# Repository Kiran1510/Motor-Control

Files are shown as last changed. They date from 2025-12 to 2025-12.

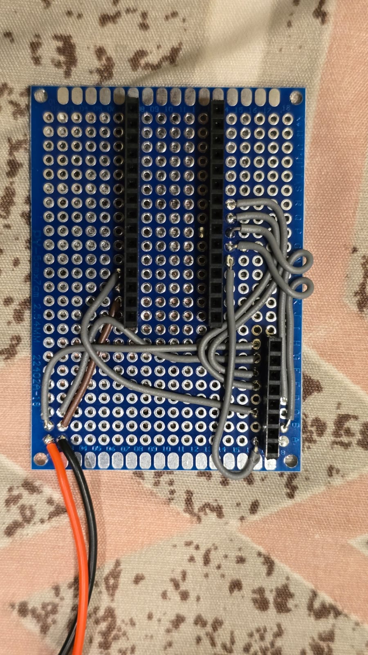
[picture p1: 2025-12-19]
Docs/pcb prototype.jpeg

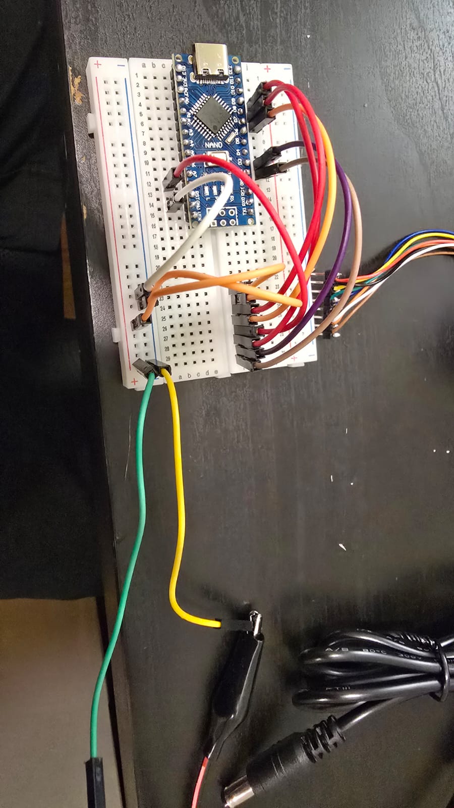
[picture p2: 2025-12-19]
Docs/prototype.jpeg

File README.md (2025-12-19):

# Motor Control System

A precision motor control system using Arduino for angle control with encoder feedback, developed as part of a self-balancing cube project.

## Overview

This project implements a Bang-Bang based control system for angular positioning using a Nidec 24H motor with integrated encoder feedback. The system is designed for applications requiring accurate motor positioning and velocity control.

## Hardware Components

### Electronics
- **Motor**: Nidec 24H brushless motor with encoder
- **Microcontroller**: Arduino-compatible board
- **Custom PCB**: KiCAD design included for motor driver interface

### Specifications
- Encoder resolution: For every 360 degrees the motor revolves, the motor shows 200 step counts.
- Control frequency: None, since this is an adaptive Bang-Bang type controller.
- Input voltage: 8~12V DC (8V is recommended for better accuracy as the speed of the motor seems to be directly proportional to the voltage)

## Project Structure
```
Motor-Control/
├── Firmware/
│   └── angle_control_nidec.ino    # Main Arduino control code
├── Hardware/
│   ├── Self Balancing Cube.kicad_pcb
│   ├── Self Balancing Cube.kicad_sch
│   └── Self Balancing Cube.kicad_pro
├── Docs/
│   └── KiCAD schematic.png        # Circuit schematic
└── README.md
```

## Features

- **PID Control**: Tunable PID parameters for precise angle control
- **Encoder Feedback**: Real-time position tracking
- **Serial Interface**: Monitor and adjust parameters via serial communication
- **Adaptive Control**: [Add if you implemented adaptive bang-bang or other features]

## Setup Instructions

### Hardware Setup

1. Flash the Arduino with `angle_control_nidec.ino`
2. Connect the Nidec motor according to the schematic in `/Docs`
3. Ensure proper power supply connections
4. Connect encoder outputs to specified Arduino pins

### Software Requirements

- Arduino IDE (version 1.8.x or higher)
- Libraries listed in the code

### Installation
```bash
# Clone the repository
git clone https://github.com/Kiran1510/Motor-Control.git

# Open the Arduino sketch
cd Motor-Control/Firmware
# Open angle_control_nidec.ino in Arduino IDE
```

## Usage

1. Upload the firmware to your Arduino board
2. Open Serial Monitor (9600 baud)
3. Send commands to control motor position. The commands are listed in the serial monitor.

## Control Parameters

I've used a Bang-Bang type controller for running this motor since it is an industrial type motor that isn't designed for precise angle outputs. The motor lacks proper documentation or datasheets, hence all of the knowledge 
I've learned from it is by trial and error. The pinouts for the motor and their functions is included in the arduino code.

## PCB Design

The custom PCB design files are available in the `/Hardware` directory. The board includes:
- Motor driver interface
- Encoder signal conditioning
- Power regulation

View the KiCAD files directly on GitHub for 2D/3D visualization of the PCB design.

## Troubleshooting

**Motor overshooting target position:**
- Make sure voltage is 8V minimum and increase voltage to 12V if no improvement in performance
- Check encoder connections

**Encoder reading errors:**
- Verify encoder power supply
- Check signal wire integrity
- Ensure proper pull-up resistors

## Future Improvements

- [ ] Implement velocity control
- [ ] Implement PID Control and compare with this current approach
- [ ] Optimize control loop timing
- [ ] Add temperature monitoring

## Project Context

This motor control system was developed as a personal project and part of a self-balancing cube project for my personal interest in controls systems engineering. The system demonstrates precision control techniques applicable to robotics and mechatronics applications.

## Author

**Kiran Sairam**
- MS Robotics, Northeastern University

## License

MIT License

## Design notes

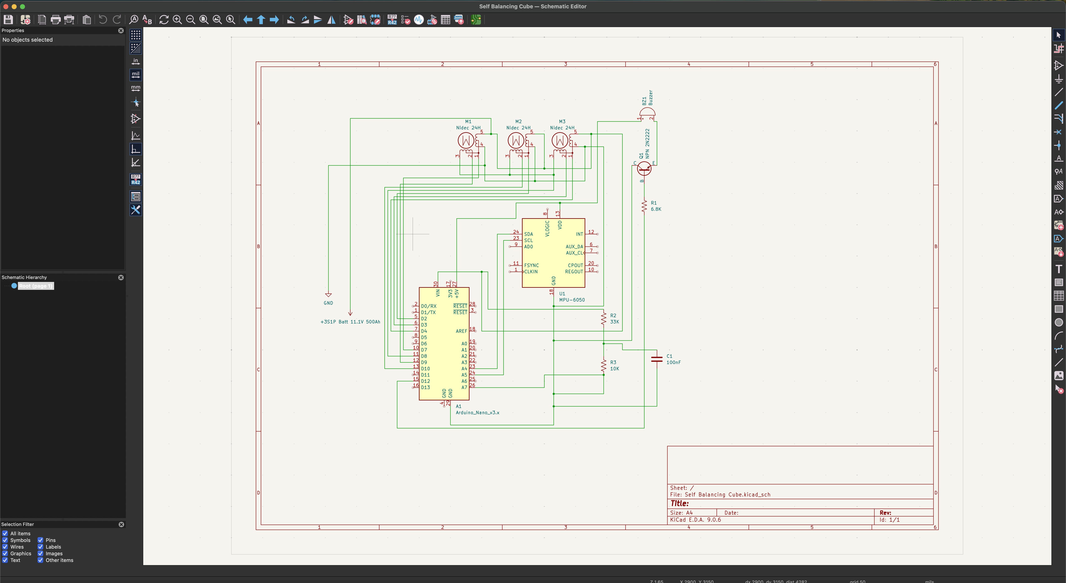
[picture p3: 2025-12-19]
Docs/KiCAD schematic.png

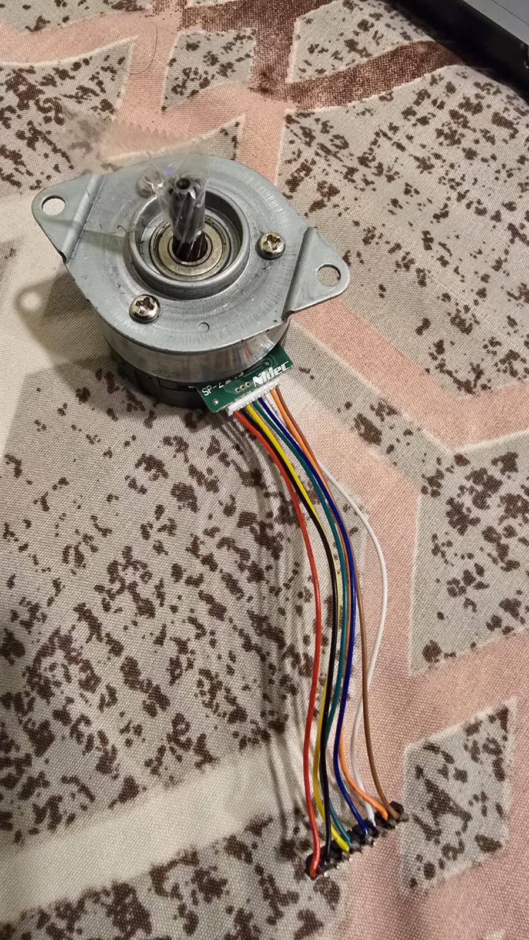
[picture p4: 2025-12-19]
Docs/motor.jpeg

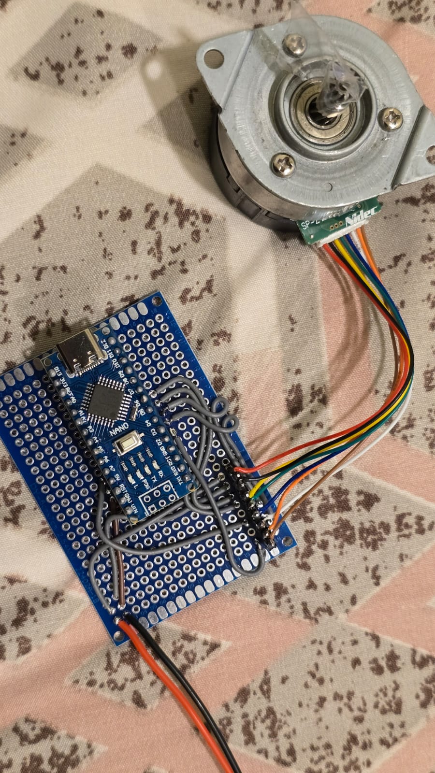
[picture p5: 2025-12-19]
Docs/finished driver.jpeg

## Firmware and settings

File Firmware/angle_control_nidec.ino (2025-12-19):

// Nidec 24H404H070 - Adaptive Bang-Bang Control
// Learns the motor's behavior and adapts pulse sizes
//
// Motor pins (8..1 on the PCB header):
// 8: +12V (VM)  -> Bench PSU +12V  (NOT to Arduino)
// 7: GND        -> Bench PSU GND + Arduino GND (common ground)
// 6: BRAKE (active LOW)        -> D6
// 5: RUN (PWM, active LOW)     -> D5
// 4: DIR (direction)           -> D4
// 3: +5V encoder Vcc           -> 5V
// 2: Encoder B (CHB)           -> D3 (unused here)
// 1: Encoder A (CHA)           -> D2 (+10k pullup to 5V strongly recommended)

const uint8_t PIN_DIR   = 4;
const uint8_t PIN_RUN   = 5;  // PWM, ACTIVE-LOW
const uint8_t PIN_BRAKE = 6;
const uint8_t PIN_ENC_A = 2;  // CHA only

// ---------- Encoder state ----------
volatile long encoderCount = 0;
volatile bool dirForward   = true;

const int   CPR           = 200;
const float DEG_PER_COUNT = 360.0 / CPR;

// ---------- Motion tuning ----------
const int   STOP_TOL_COUNTS = 2;  // ±3.6° tolerance
const unsigned long MOVE_TIMEOUT_MS = 20000;

// Single power level - we'll only vary pulse duration
const uint8_t MOVE_POWER = 30;

// Adaptive pulse timing (will learn and adjust)
int basePulseTime = 25;  // Start with 25ms pulses
const int minPulse = 15;
const int maxPulse = 50;

// =====================================================
//                      ENCODER ISR
// =====================================================
void encoderISR() {
  if (dirForward) {
    encoderCount++;
  } else {
    encoderCount--;
  }
}

// =====================================================
//                    MOTOR HELPERS
// =====================================================
void motorBrake(bool on) {
  digitalWrite(PIN_BRAKE, on ? LOW : HIGH);
}

void motorSetDirection(bool forward) {
  dirForward = forward;
  digitalWrite(PIN_DIR, forward ? HIGH : LOW);
}

void motorSetPower(uint8_t power) {
  analogWrite(PIN_RUN, 255 - power);
}

void motorStop() {
  motorSetPower(0);
}

long getEncoderCount() {
  noInterrupts();
  long c = encoderCount;
  interrupts();
  return c;
}

// Execute a single movement pulse and return counts moved
int executePulse(int pulseTimeMs) {
  long startCount = getEncoderCount();
  
  motorSetPower(MOVE_POWER);
  delay(pulseTimeMs);
  
  motorStop();
  motorBrake(true);
  delay(100);  // Hard brake
  motorBrake(false);
  delay(150);  // Settle time
  
  long endCount = getEncoderCount();
  return abs(endCount - startCount);
}

// =====================================================
//                  MOVE TO TARGET ANGLE
// =====================================================
void moveToAngle(float targetDeg) {
  long targetCount = lround(targetDeg * CPR / 360.0);

  motorBrake(false);
  delay(150);

  long current = getEncoderCount();
  long err = targetCount - current;

  if (abs(err) <= STOP_TOL_COUNTS) {
    Serial.println("[Move] Already within tolerance.");
    motorStop();
    motorBrake(true);
    return;
  }

  Serial.print("\n[Move] Target = ");
  Serial.print(targetDeg, 1);
  Serial.print("° (");
  Serial.print(targetCount);
  Serial.print(" counts), Current = ");
  Serial.print(current * DEG_PER_COUNT, 1);
  Serial.print("° (");
  Serial.print(current);
  Serial.println(" counts)");

  bool needForward = (targetCount > current);
  motorSetDirection(needForward);
  delay(100);

  unsigned long moveStart = millis();
  int moveCount = 0;
  int overshootCount = 0;

  while (true) {
    long currentCount = getEncoderCount();
    long eCount = targetCount - currentCount;
    long absErr = abs(eCount);

    float currentDeg = currentCount * DEG_PER_COUNT;

    // Check if reached
    if (absErr <= STOP_TOL_COUNTS) {
      Serial.println("[Move] Target reached!");
      break;
    }

    // Check for overshoot
    bool shouldBeForward = (eCount > 0);
    if (shouldBeForward != needForward) {
      overshootCount++;
      if (overshootCount > 2) {
        Serial.println("[Move] Oscillating - stopping here");
        break;
      }
      
      Serial.println("[Overshoot - reversing]");
      
      // Reduce pulse time when we overshoot
      basePulseTime = max(minPulse, basePulseTime - 3);
      Serial.print("Reducing pulse time to ");
      Serial.println(basePulseTime);
      
      motorStop();
      motorBrake(true);
      delay(250);
      motorBrake(false);
      delay(100);
      
      needForward = shouldBeForward;
      motorSetDirection(needForward);
      delay(100);
    }

    // Calculate pulse duration based on distance
    int pulseTime;
    if (absErr <= 2) {
      pulseTime = minPulse;  // Minimum pulse for last count
    } else if (absErr <= 5) {
      pulseTime = basePulseTime;  // Adaptive base pulse
    } else if (absErr <= 15) {
      pulseTime = basePulseTime + 10;
    } else {
      pulseTime = basePulseTime + 20;
    }
    
    pulseTime = constrain(pulseTime, minPulse, maxPulse);

    Serial.print("Pos: ");
    Serial.print(currentDeg, 1);
    Serial.print("° | Err: ");
    Serial.print(absErr);
    Serial.print(" counts | Pulse: ");
    Serial.print(pulseTime);
    Serial.println("ms");

    // Execute the pulse
    int countsMoved = executePulse(pulseTime);
    moveCount++;

    // Adaptive learning - if we moved too far, reduce pulse time
    if (absErr <= 5 && countsMoved > absErr) {
      basePulseTime = max(minPulse, basePulseTime - 2);
      Serial.print("Moved too far - reducing base pulse to ");
      Serial.println(basePulseTime);
    }
    // If we barely moved, increase pulse time
    else if (absErr > 3 && countsMoved < 1) {
      basePulseTime = min(maxPulse, basePulseTime + 2);
      Serial.print("Moved too little - increasing base pulse to ");
      Serial.println(basePulseTime);
    }

    // Safety timeout
    if (millis() - moveStart > MOVE_TIMEOUT_MS) {
      Serial.println("[Move] TIMEOUT");
      break;
    }

    // Give up if too many moves without progress
    if (moveCount > 50) {
      Serial.println("[Move] Too many iterations - stopping");
      break;
    }
  }

  motorStop();
  motorBrake(true);
  delay(150);

  long finalCount = getEncoderCount();
  float finalDeg = finalCount * DEG_PER_COUNT;
  float finalError = finalDeg - targetDeg;

  Serial.print("[Final] Position = ");
  Serial.print(finalDeg, 1);
  Serial.print("° (");
  Serial.print(finalCount);
  Serial.print(" counts) | Error = ");
  Serial.print(finalError, 1);
  Serial.print("° | Learned pulse time: ");
  Serial.print(basePulseTime);
  Serial.println("ms");
  
  if (abs(finalError) <= 5.4) {
    Serial.println("Status: ACCEPTABLE");
  } else {
    Serial.println("Status: OUT OF SPEC");
  }
}

// =====================================================
//                      SETUP
// =====================================================
void setup() {
  Serial.begin(115200);
  delay(1000);

  pinMode(PIN_DIR,   OUTPUT);
  pinMode(PIN_RUN,   OUTPUT);
  pinMode(PIN_BRAKE, OUTPUT);
  pinMode(PIN_ENC_A, INPUT_PULLUP);

  digitalWrite(PIN_DIR, LOW);
  digitalWrite(PIN_RUN, HIGH);
  digitalWrite(PIN_BRAKE, LOW);
  
  attachInterrupt(digitalPinToInterrupt(PIN_ENC_A), encoderISR, CHANGE);

  encoderCount = 0;

  Serial.println("=== Nidec 24H Adaptive Bang-Bang Control (8V) ===");
  Serial.println("CPR: 200, Resolution: 1.8°, Tolerance: ±3.6°");
  Serial.println("The system will learn optimal pulse duration");
  Serial.println("\nCommands:");
  Serial.println("  <angle> - Move to angle");
  Serial.println("  z - Zero position");
  Serial.println();
}

// =====================================================
//                       LOOP
// =====================================================
void loop() {
  if (Serial.available() > 0) {
    String line = Serial.readStringUntil('\n');
    line.trim();
    if (line.length() == 0) return;

    if (line.equalsIgnoreCase("z") || line.equalsIgnoreCase("zero")) {
      noInterrupts();
      encoderCount = 0;
      interrupts();
      Serial.println("[Zero] Position reset");
      return;
    }

    float angle = line.toFloat();
    if (!line.equals("0") && angle == 0.0) {
      Serial.println("[Error] Invalid angle");
      return;
    }

    moveToAngle(angle);
    Serial.println();
  }
}

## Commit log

2025-12-19 Adding files
    [Self Balancing Cube.kicad_pcb, Self Balancing Cube.kicad_sch]
2025-12-19 Added more images of physical circuit and motor
